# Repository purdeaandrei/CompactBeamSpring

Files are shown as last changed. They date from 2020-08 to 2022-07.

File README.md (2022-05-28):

# Compact Beamspring controller.

This controller only supports new style card edge connectors only, and it requires the side
of the card edge connector to be cut off, and the pins be bent 90 degress.

## Images

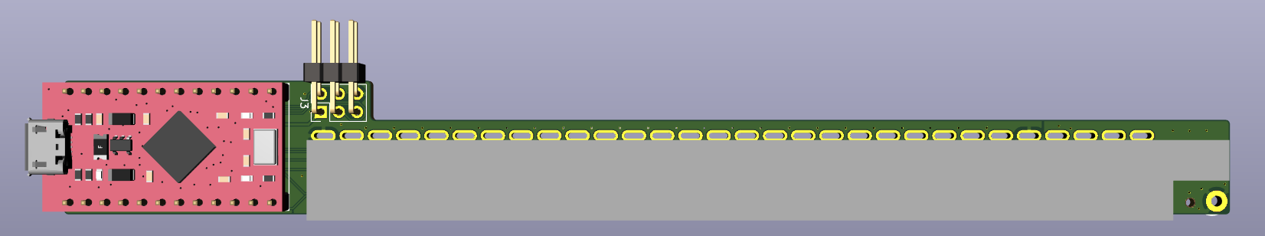
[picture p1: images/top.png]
Top of the controller board

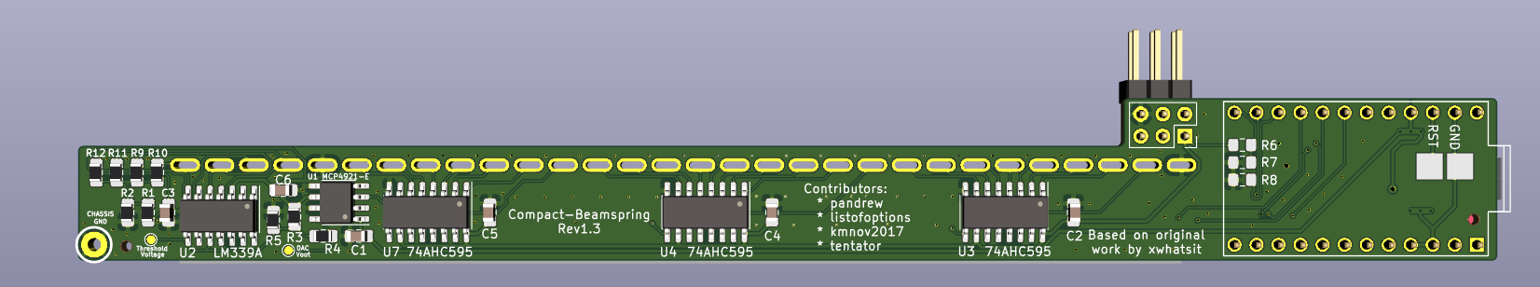
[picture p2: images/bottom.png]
Bottom of the controller board


## Other controllers in this family:
* https://github.com/purdeaandrei/CompactBeamSpringAdditionalExpansion
* https://github.com/purdeaandrei/SMDModelFController
* https://github.com/purdeaandrei/SMDModelFController/tree/extra_columns
* https://github.com/purdeaandrei/SMD4704KishsaverClassModelFController
* https://github.com/listofoptions/TH-XWhatsIt

## Origins and license

This project is based on the Through-hole xwhatsit by listofoptions, which is un turn
based on the capsense controllers by XWhatsIt
(Tom Wong-Cornall). original liscencure holds, as well as CERN OSH
(compatible license).

original implementation of Tom Wong-Cornall's controller documented here

http://downloads.cornall.co/ibm-capsense-usb-web/ibm-capsense-usb.html

Working theory of operation is under the previous link.

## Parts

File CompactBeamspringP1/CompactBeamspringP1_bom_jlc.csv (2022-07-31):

Comment | Designator | Footprint | LCSC Part #
0U1 | C2,C6,C5,C3,C1,C4 | C_0805_2012Metric_Pad1.15x1.40mm_HandSolder | C49678
1K | R2 | R_0805_2012Metric_Pad1.15x1.40mm_HandSolder | C17513
20K | R4,R3 | R_0805_2012Metric_Pad1.15x1.40mm_HandSolder | C4328
4K7 | R5,R1 | R_0805_2012Metric_Pad1.15x1.40mm_HandSolder | C17673
100k 1% | R9,R10,R11,R12 | R_0805_2012Metric_Pad1.15x1.40mm_HandSolder | C149504
MCP4921-E | U1 | SOIC-8_3.9x4.9mm_P1.27mm | C43499
LM339A | U2 | SOIC-14_3.9x8.7mm_P1.27mm | C74559
74AHC595 | U3,U4,U7 | SOIC-16_3.9x9.9mm_P1.27mm | C5520

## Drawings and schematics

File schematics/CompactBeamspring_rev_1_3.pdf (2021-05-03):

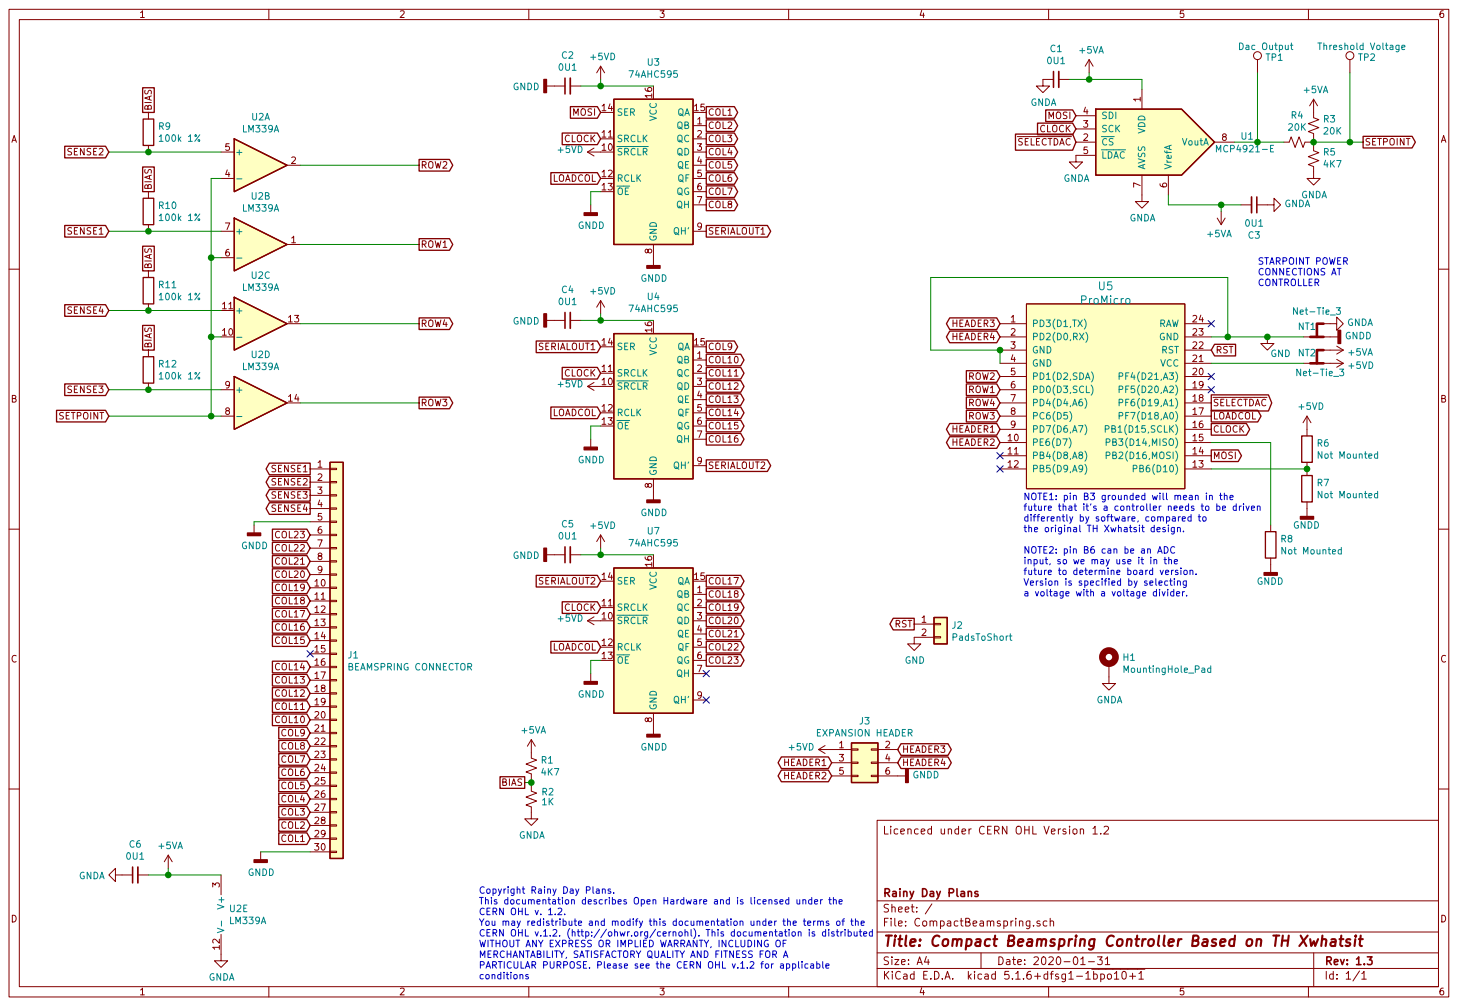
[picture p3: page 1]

future that it's a controller needs to be driven
differently by software, compared to
the original TH Xwhatsit design.

NOTE2: pin B6 can be an ADC
input, so we may use it in the
future to determine board version. Version is specified by selecting

a voltage with a voltage divider.

Licenced under CERN OHL Version 1.2

Copyright Rainy Day Plans.
This documentation describes Open Hardware and is licensed under the CERN OHL v. 1.2. You may redistribute and modify this documentation under the terms of the

File: CompactBeamspring.sch Sheet: / Rainy Day Plans

Id: 1/1 Title: Compact Beamspring Controller Based on TH Xwhatsit

CERN OHL v.1.2. (http://ohwr.org/cernohl). This documentation is distributed WITHOUT ANY EXPRESS OR IMPLIED WARRANTY, INCLUDING OF MERCHANTABILITY, SATISFACTORY QUALITY AND FITNESS FOR A

PARTICULAR PURPOSE. Please see the CERN OHL v.1.2 for applicable
conditions

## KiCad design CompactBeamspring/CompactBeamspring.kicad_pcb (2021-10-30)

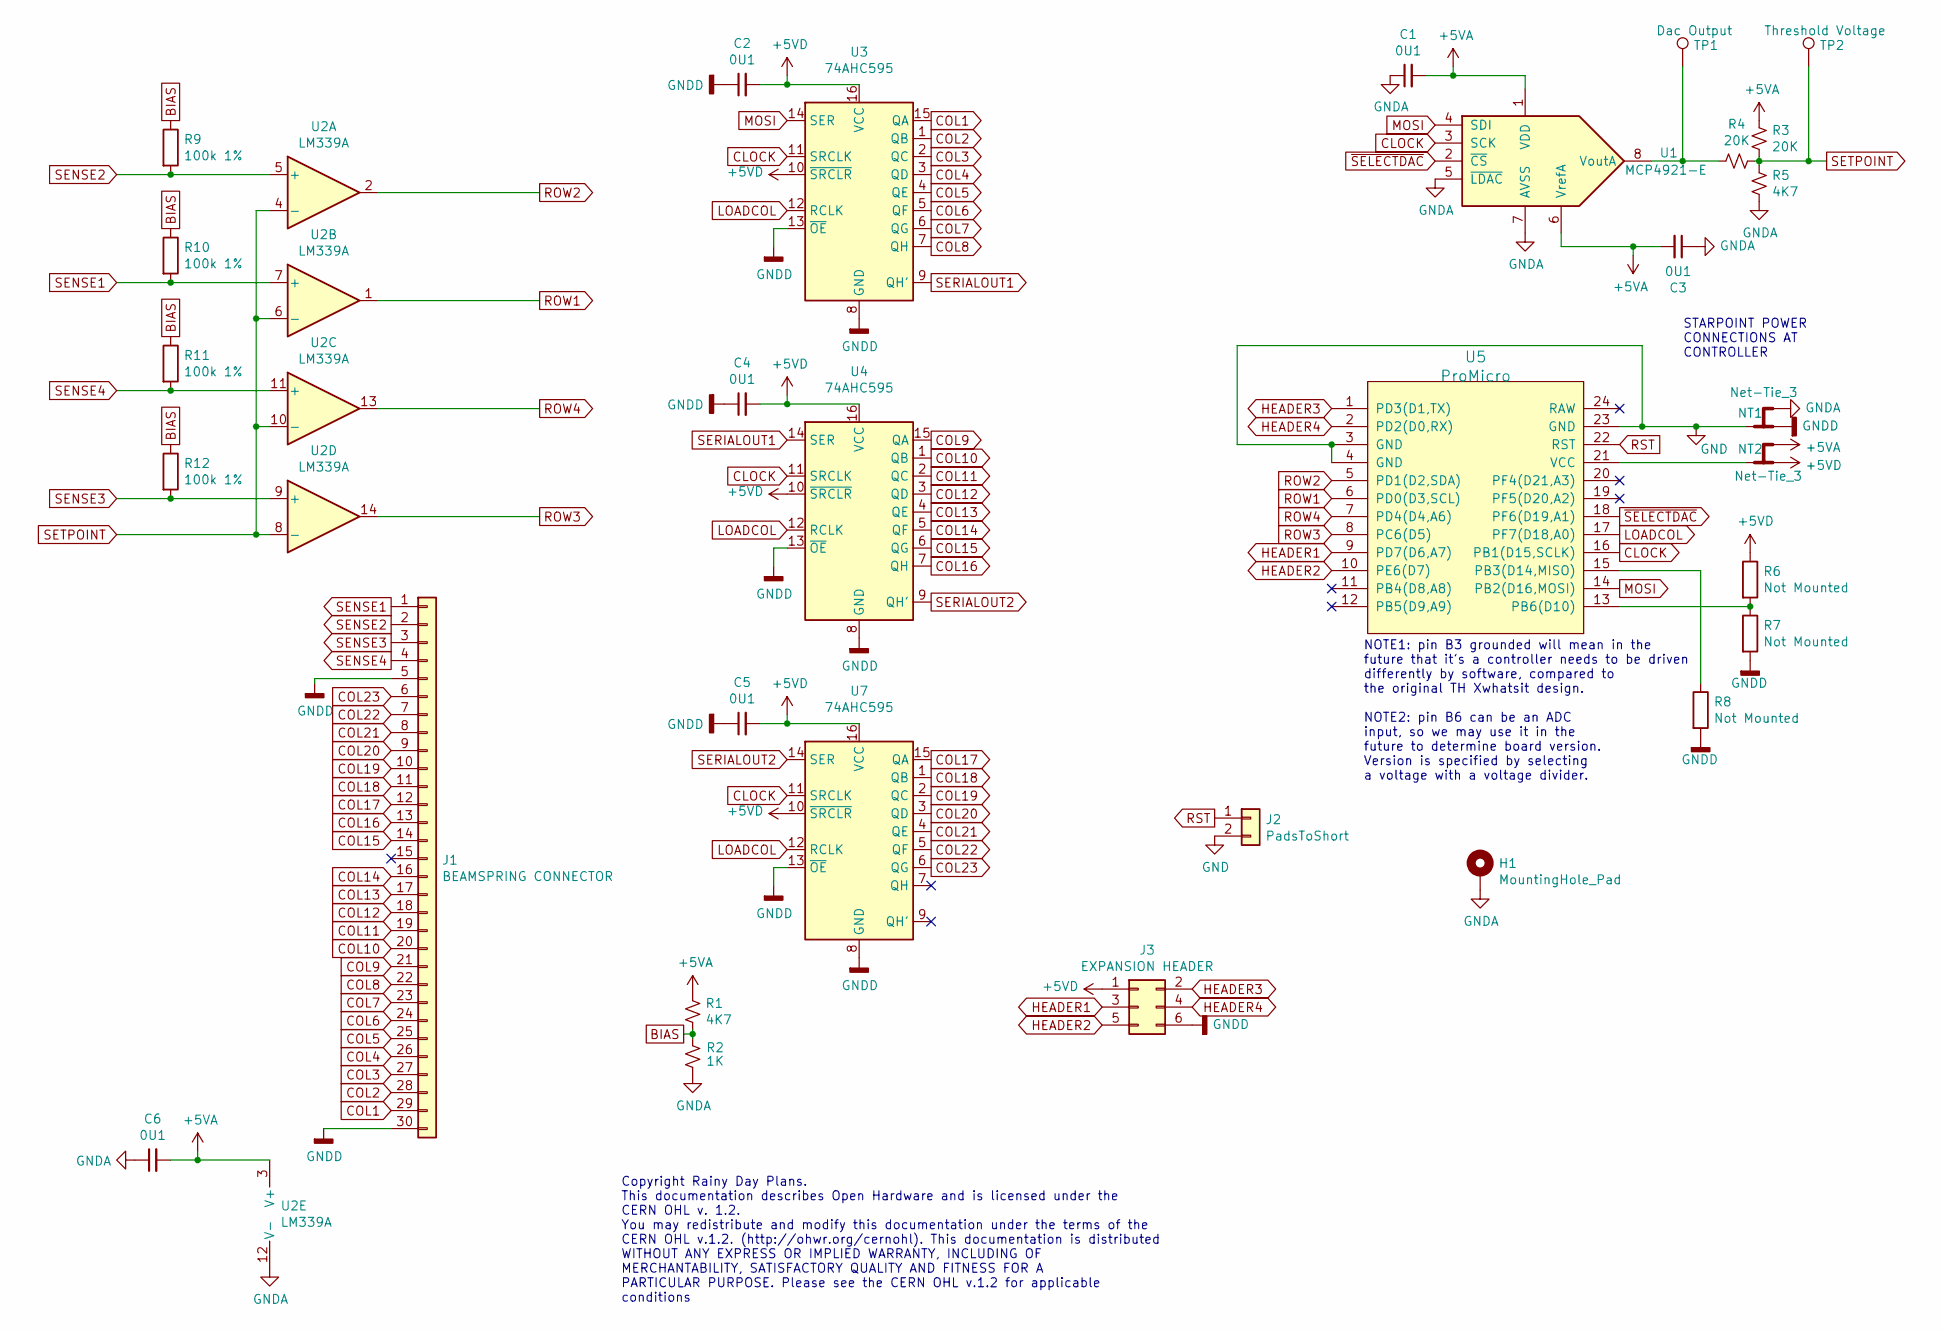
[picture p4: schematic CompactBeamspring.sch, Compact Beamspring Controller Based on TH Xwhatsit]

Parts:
C1, C2, C3, C4, C5, C6: 0U1; C_0805_2012Metric_Pad1.15x1.40mm_HandSolder; LCSC C49678
H1: MountingHole_Pad; ChassisGnd
J1: BEAMSPRING CONNECTOR; 30-pin-universal-beamspring-connector_v3_onlyflat
J2: PadsToShort
J3: EXPANSION HEADER; PinHeader_2x03_P2.54mm_Vertical
NT1, NT2: Net-Tie_3; NetTie-3_THT_Pad0.3mm
R1, R5: 4K7; R_0805_2012Metric_Pad1.15x1.40mm_HandSolder; LCSC C17673
R2: 1K; R_0805_2012Metric_Pad1.15x1.40mm_HandSolder; LCSC C17513
R3, R4: 20K; R_0805_2012Metric_Pad1.15x1.40mm_HandSolder; LCSC C4328
R6, R7, R8: Not Mounted; R_0805_2012Metric_Pad1.15x1.40mm_HandSolder
R9, R10, R11, R12: 100k 1%; R_0805_2012Metric_Pad1.15x1.40mm_HandSolder; LCSC C17407
TP1: Dac Output; TestPoint_Pad_D1.0mm
TP2: Threshold Voltage; TestPoint_Pad_D1.0mm
U1: MCP4921-E; SOIC-8_3.9x4.9mm_P1.27mm; LCSC C43499
U2: LM339A; SOIC-14_3.9x8.7mm_P1.27mm; LCSC C74559
U3, U4, U7: 74AHC595; SOIC-16_3.9x9.9mm_P1.27mm; LCSC C5520
U5: ProMicro

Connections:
+5VA: C1.2, C3.2, C6.2, NT2.3, R1.1, R3.2, U1.1 (VDD), U1.6 (VrefA), U2.3 (V+)
+5VD: C2.2, C4.2, C5.2, J3.1, NT2.1, R6.1, U3.10 (~SRCLR), U3.16 (VCC), U4.10 (~SRCLR), U4.16 (VCC), U7.10 (~SRCLR), U7.16 (VCC)
BIAS: R1.2, R2.2, R9.1, R10.1, R11.1, R12.1
CLOCK: U1.3 (SCK), U3.11 (SRCLK), U4.11 (SRCLK), U5.16 (PB1(D15,SCLK)), U7.11 (SRCLK)
COL1: J1.29, U3.15 (QA)
COL2: J1.28, U3.1 (QB)
COL3: J1.27, U3.2 (QC)
COL4: J1.26, U3.3 (QD)
COL5: J1.25, U3.4 (QE)
COL6: J1.24, U3.5 (QF)
COL7: J1.23, U3.6 (QG)
COL8: J1.22, U3.7 (QH)
COL9: J1.21, U4.15 (QA)
COL10: J1.20, U4.1 (QB)
COL11: J1.19, U4.2 (QC)
COL12: J1.18, U4.3 (QD)
COL13: J1.17, U4.4 (QE)
COL14: J1.16, U4.5 (QF)
COL15: J1.14, U4.6 (QG)
COL16: J1.13, U4.7 (QH)
COL17: J1.12, U7.15 (QA)
COL18: J1.11, U7.1 (QB)
COL19: J1.10, U7.2 (QC)
COL20: J1.9, U7.3 (QD)
COL21: J1.8, U7.4 (QE)
COL22: J1.7, U7.5 (QF)
COL23: J1.6, U7.6 (QG)
GND: J2.2, NT1.2, U5.3 (GND), U5.4 (GND), U5.23 (GND)
GNDA: C1.1, C3.1, C6.1, H1.1, NT1.3, R2.1, R5.1, U1.5 (~LDAC~), U1.7 (AVSS), U2.12 (V-)
GNDD: C2.1, C4.1, C5.1, J1.5, J1.30, J3.6, NT1.1, R7.2, R8.2, U3.8 (GND), U3.13 (~OE), U4.8 (GND), U4.13 (~OE), U7.8 (GND), U7.13 (~OE)
HEADER1: J3.3, U5.9 (PD7(D6,A7))
HEADER2: J3.5, U5.10 (PE6(D7))
HEADER3: J3.2, U5.1 (PD3(D1,TX))
HEADER4: J3.4, U5.2 (PD2(D0,RX))
LOADCOL: U3.12 (RCLK), U4.12 (RCLK), U5.17 (PF7(D18,A0)), U7.12 (RCLK)
MOSI: U1.4 (SDI), U3.14 (SER), U5.14 (PB2(D16,MOSI))
unnamed: NT2.2, U5.21 (VCC)
unnamed: R4.2, TP1.1, U1.8 (VoutA)
unnamed: R6.2, R7.1, U5.13 (PB6(D10))
unnamed: R8.1, U5.15 (PB3(D14,MISO))
ROW1: U2.1, U5.6 (PD0(D3,SCL))
ROW2: U2.2, U5.5 (PD1(D2,SDA))
ROW3: U2.14, U5.8 (PC6(D5))
ROW4: U2.13, U5.7 (PD4(D4,A6))
RST: J2.1, U5.22 (RST)
SENSE1: J1.1, R10.2, U2.7 (+)
SENSE2: J1.2, R9.2, U2.5 (+)
SENSE3: J1.3, R12.2, U2.9 (+)
SENSE4: J1.4, R11.2, U2.11 (+)
SERIALOUT1: U3.9 (QH'), U4.14 (SER)
SERIALOUT2: U4.9 (QH'), U7.14 (SER)
SETPOINT: R3.1, R4.1, R5.2, TP2.1, U2.4 (-), U2.6 (-), U2.8 (-), U2.10 (-)
~SELECTDAC: U1.2 (~CS~), U5.18 (PF6(D19,A1))

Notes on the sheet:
Copyright Rainy Day Plans. This documentation describes Open Hardware and is licensed under the CERN OHL v. 1.2. You may redistribute and modify this documentation under the terms of the CERN OHL v.1.2. (http://ohwr.org/cernohl). This documentation is distributed WITHOUT ANY EXPRESS OR IMPLIED WARR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
NOTE1: pin B3 grounded will mean in the future that it's a controller needs to be driven differently by software, compared to the original TH Xwhatsit design. NOTE2: pin B6 can be an ADC input, so we may use it in the future to determine board version. Version is specified by selecting a voltage wi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
STARPOINT POWER CONNECTIONS AT CONTROLLER

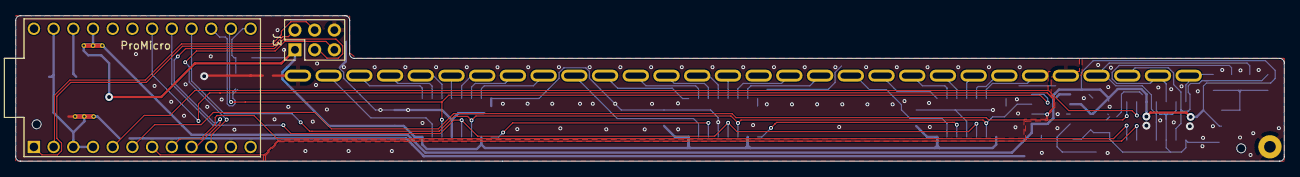
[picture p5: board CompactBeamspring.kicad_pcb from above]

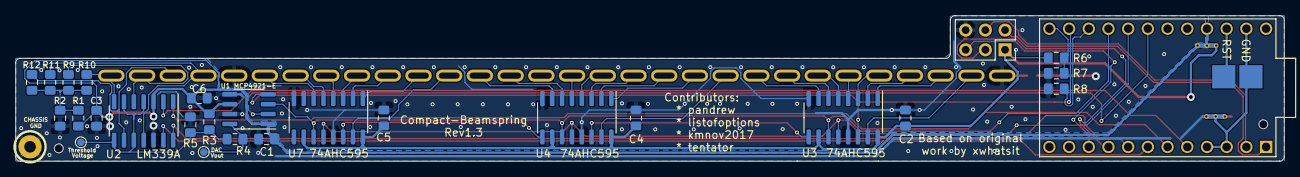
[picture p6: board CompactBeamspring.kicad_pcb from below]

Board: 2 copper layers, 163.6 x 18.8 mm, 32 parts (29 on the bottom side), 53 nets.

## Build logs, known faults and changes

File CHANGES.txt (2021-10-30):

January 31St, 2020:
    user: Listofoptions
        done:
            initial commit, completed main controller board and schematic
        todo:
            plugboard wiring and socket / connector positioning
            physical hardware testing
            firmware 
            firmware testing

Febuary 3rd, 2020
    user: Listofoptions
        done:
            moved setpoint decoupler cap to hopefully lower interferance with
            relatively high frequency output from the comparitors
            
            connector positioning for plugboard complete
            
            moved sense connector to allow better placement of corresponding
            socket on plugboards (sense traces needed more room on plugboards)
        todo:
            displaywriter plugboard wiring
            physical hardware testing
            firmware
            firmware testing
Febuary 4th, 2020
    user: listofoptions
        done:
            added ground strap points to plugboards, and positioned them to
            align with the ground strap on the main board
            
            displaywriter plugboard completely wired
            
            added cutouts in plugboards for expasion header wiring
        todo:
            maybe add more grounding straps to aid in mechanical strength
            (i intend to use metal standoffs to connect the plugboards and 
            main board)
            
            physical hardware testing
            firmware
            firmware testing
August 14th, 2020
    user: listofoptions
        done:
            complete smd rework 
        todo:
            fine tune the castelations
            add cutouts for throughhole components to pigybacking plugboards
            rewire and resize plugboards for max compatibility
            physical hardware testing
            firmware
            firmware testing

Unknown Date
    user: purdeandrei
        done:
            Renamed to Compact Beamspring Controller. First revision seen by the public is Rev. 1.3
            Trimmed down design to be specific to beamspring controllers
            Removed usage of resistor networks, now using individual resistors.
            Reverted some pinout changes to make it compatible to the original TH-Xwhatsit
            PCB layout re-done from scratch, to be as small as possible.
May 3, 2021
    user: purdeaandrei
        done:
            Updated Pro Micro schematic symbol, to correct pin names, and be more verbose.
            Added schematics in pdf form.

Oct 30, 2021
    user: purdeaandrei
        done:
            Removed datasheets
            Updated some licensing info
            Pro Micro 3D model: added pins
            Solenoid header, use 90-degree 3d model
            Added rendered images, tweaked readme

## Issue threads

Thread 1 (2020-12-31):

IBM Beamspring model 3278 A02 / 3279 2C top panel controller

DeusLb, 2020-12-31:
Hello there,

I’m pulling this request because I’m kinda stuck with my current project.

I just got a Beamspring model 3278 A02 witch has a top panel with 3 buttons and 3 diodes and I’m looking for a solution to connect them to the main pcb and/or use it.

someone already did it but I have no idea how ... https://youtu.be/_UmhT_NL8Jo

Thank you in advance :) and happy new year !!

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

purdeaandrei, 2020-12-31:
Hey!

Nice beamer!
I have no idea how it's done on that video, and also i'm not familiar with any external conversion options that may or may not exist. I've see this on ebay, but don't know anything about it: https://www.ebay.com/itm/PCkbd-3278-USBC-Converter-for-IBM-Beamspring-3278-Keyboard/164310011368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
And I especially don't know if it supports or not the extra switches and lights.

When it comes to internal conversion, you could do it with one of the pro micro-based newer xwhatsit converters by soldering directly to unused pro micro pins, and then writing custom C code. (either this Compact Beamspring controller project will do, or the TH controller https://github.com/listofoptions/TH-XWhatsIt. I still have 5 compact beamspring converters in stock if you're interested. This is the related discussion forum by the way: https://deskthority.net/viewtopic.php?f=50&t=24512 ) And you will also need a separate solenoid driver.

(
More Options:
Another option would be a DMA Commonsense controller, but I can't help you with that.

Also it would be technically possible to use an original xwhatsit beamspring controller as well, either by soldering directly to the SMD TQFP chip pins, (which is very fine pitch, so fairly hard, depending on soldering skills), or by using some kind of IO extender circuit on the expansion header.
)

DeusLb, 2020-12-31:
Hi !

Thank you very much for your reply.

So, in order to make this work, I need more entries in order to connect the top panel's PCB to the main PCB correct ? Since I only have a "standard" controller, I'll need another one that gives me the opportunity to get more entries like the TH controller or the Compact Beamspring controller ?

Thank you again,

Happy new year ;)

purdeaandrei, 2021-01-01:
What do you mean by 'standard' controller? Do you have one of these?:
https://geekhack.org/index.php?action=dlattach;topic=58138.0;attach=64349;image

DeusLb, 2021-01-01:
Yes this is the one, got it from Orihalcon on eBay

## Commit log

2020-08-16 Added compact beamspring-only version
    [TH-XWhatsIt-B_Cu.gbr, TH-XWhatsIt-B_Mask.gbr, TH-XWhatsIt-B_Paste.gbr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]
2020-08-17 remove old gerber files
2020-08-17 added version selection resistor divider pads
    [TH-XWhatsIt.kicad_pcb, TH-XWhatsIt.sch]
2020-08-17 cleaned away some extra copper traces around pads connected to copper fills
    [TH-XWhatsIt.kicad_pcb]
2020-08-17 cleaned up cuts in the copper fill
    [TH-XWhatsIt.kicad_pcb]
2020-08-17 a bit more copper pour-related cleanups
    [TH-XWhatsIt.kicad_pcb]
2020-08-17 Added chassis ground, and added some silkscreen
    [TH-XWhatsIt.kicad_pcb, TH-XWhatsIt.sch]
2020-08-17 fixed net tie thermal relief
    [TH-XWhatsIt.kicad_pcb]
2020-08-17 moved chassis gnd connection a little in order to get 3 connections to gnd plane
    [TH-XWhatsIt.kicad_pcb]
2020-08-17 added copper fill keepout to shorted configuration resistor
    [TH-XWhatsIt.kicad_pcb]
2020-08-17 added forgotten chassis gnd footprint
2020-08-17 more tweaks: corners bigger radius, some more rework on traces, and copper fills
    [TH-XWhatsIt.kicad_pcb]
2020-08-17 added panelized pcb
    [beam_p.kicad_pcb]
2020-08-17 added tooling hole
2020-08-17 added tooling holes to existing panel
    [beam_p.kicad_pcb]
2020-08-17 single pcb: added tooling holes, position is only good for when pcbs are panelized back-to-back
    [TH-XWhatsIt.kicad_pcb]
2020-08-17 disable the keep upright feature on the single pcb, usefule for future panelizations
    [TH-XWhatsIt.kicad_pcb]
2020-08-17 rotate silkscreens into proper orientation on panel
    [beam_p.kicad_pcb]
2020-08-17 added lcsc part number to a bunch of components. Still todo: comparator and 74hc595
    [TH-XWhatsIt.sch]
2020-08-18 added lcsc numbers for remaining chips, changed some silkscreen to match parts, removed stay-upright flag from all silkscreen, etc...
    [TH-XWhatsIt.kicad_pcb, TH-XWhatsIt.sch, beam_p.kicad_pcb]
2020-08-18 added panelized gerbers, bom and cpl files
    [beam_p-B_Cu.gbr, beam_p-B_Mask.gbr, beam_p-B_Paste.gbr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]
2020-08-18 rotated pro micro silkscreen
    [TH-XWhatsIt.kicad_pcb, beam_p.kicad_pcb]
2020-08-18 added silkscreen for jlcpcb order number to panel
    [beam_p.kicad_pcb]
2020-08-18 panel: regenerated gerbers
    [beam_p-B_Cu.gbr, beam_p-B_Mask.gbr, beam_p-B_Paste.gbr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]
2020-08-18 improved single board net tie to copper fill connection type
    [TH-XWhatsIt.kicad_pcb]
2020-08-18 single board: tightened up copper fill zones around board
    [TH-XWhatsIt.kicad_pcb]
2020-08-18 panel: tightened up and fixed copper fills, changed net tie to solid clearance
    [beam_p.kicad_pcb]
2020-08-18 beam_p_gerbers: regenerated
    [beam_p-B_Cu.gbr, beam_p-B_Mask.gbr, beam_p-B_Paste.gbr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]
2020-08-19 single board: move RN farther away from resistor, hopefully resolving the too little soldering space warning from the assembly house
    [TH-XWhatsIt.kicad_pcb]
2020-08-19 removed old panel, will re-do now
    [beam_p-B_Cu.gbr, beam_p-B_Mask.gbr, beam_p-B_Paste.gbr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]
2020-08-19 removed old plugboards left-over
    [beamspring plugboard.sch, displaywriter plugboard.sch, model f plugboard.sch]
2020-08-19 Renamed project to CompactBeamspring
    [CompactBeamspring.kicad_pcb, CompactBeamspring.sch]
2020-08-19 make schematic point to the right 3d model
    [CompactBeamspring.kicad_pcb]
2020-08-19 added 2-board panel
    [CompactBeamspringP2.kicad_pcb]
2020-08-19 Added CompactBeamspringP1 1-piece panel to make smt assembly possible for low volumes
    [CompactBeamspringP1.kicad_pcb]
2020-08-19 Added auxiliary axis on the bottom left to both panels
    [CompactBeamspringP1.kicad_pcb, CompactBeamspringP2.kicad_pcb]
2020-08-19 2-panel: added silkscreen for jlcpcb part number. 1-panel already has it
    [CompactBeamspringP2.kicad_pcb]
2020-08-19 Panels: added gerbers
    [CompactBeamspringP1-B_Cu.gbr, CompactBeamspringP1-B_Mask.gbr, CompactBeamspringP1-B_Paste.gbr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]
2020-08-19 Added positioning csv files
    [CompactBeamspringP1_bom_jlc.csv, CompactBeamspringP2_bom_jlc.csv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]
2020-08-19 Fixed rotation and PosX of all components in JLCPCB positioning file
    [CompactBeamspringP1_cpl_jlc.csv, CompactBeamspringP2_cpl_jlc.csv]
2020-08-19 made it th xwhatsit software compatible, added dac testpoints, added reset shorting pads, generally reworked to be nicer
    [CompactBeamspring.kicad_pcb, CompactBeamspring.sch]
2020-08-20 More mods
    [CompactBeamspring.kicad_pcb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]
2020-08-20 Moved to individual resistors instead of resistor network, added a bit more space next to the promicro
    [CompactBeamspring.kicad_pcb, CompactBeamspring.sch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]
2020-10-25 moved gerbers into zips to make it easier to order
    [CompactBeamspringP1-B_Cu.gbr, CompactBeamspringP1-B_Mask.gbr, CompactBeamspringP1-B_Paste.gbr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]
2021-05-03 Updated Pro Micro schematic symbol, and added schematics
    [CompactBeamspring.sch]
2021-10-30 Clarified license of the footprint library
2021-10-30 Beamspring footprint: Move custom modifications back into footprint library item.
2021-10-30 Fixup wrong footprint reference
    [CompactBeamspring.sch]
2021-10-30 Updated Pro Micro and solenoid header footprint for more correct rendering
    [CompactBeamspring.kicad_pcb]
2022-02-14 Update component rotations, to match new behaviour of JLCPCB on the bottom layer
    [CompactBeamspringP1_cpl_jlc.csv, CompactBeamspringP2_cpl_jlc.csv]
2022-07-31 Updated 100k resistor LCSC part numbers
    [CompactBeamspring.sch, CompactBeamspringP1_bom_jlc.csv, CompactBeamspringP2_bom_jlc.csv]
2022-07-31 Updated shift register LCSC part number
    [CompactBeamspring.sch, CompactBeamspringP1_bom_jlc.csv, CompactBeamspringP2_bom_jlc.csv]
2022-07-31 fix rotations to match latest JLCPCB behaviour
    [CompactBeamspringP1_cpl_jlc.csv, CompactBeamspringP2_cpl_jlc.csv]
2022-09-15 Revert "Updated shift register LCSC part number"
    This reverts commit 109b71d9faab148fe864110445be2db0dc0f59e0.
    [CompactBeamspring.sch, CompactBeamspringP1_bom_jlc.csv, CompactBeamspringP2_bom_jlc.csv]
